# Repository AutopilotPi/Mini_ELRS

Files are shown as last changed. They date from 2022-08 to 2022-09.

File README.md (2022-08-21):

# Mini_ELRS

The repo is a hardware design for ELRS(https://github.com/ExpressLRS/ExpressLRS) by Kicad 6.0. The design aim to construct a 
mini elrs module which could drive brush motor directly.

There are 5 PWM channels in this board, 2 of them are with mos, and could connect to brush motor.

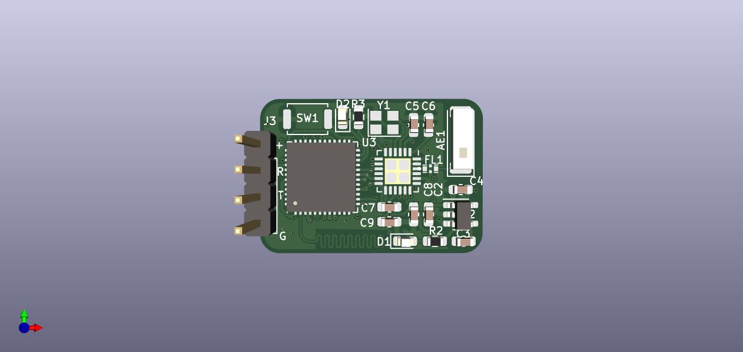
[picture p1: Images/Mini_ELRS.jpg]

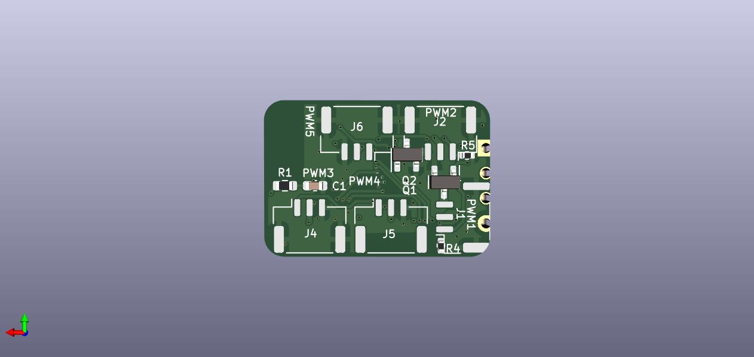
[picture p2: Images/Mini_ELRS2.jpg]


## License
Please notice that the license of this project is GPL 3.0. For hardware project, hope that you can share the changes if you make something different in the sch or pcb.

### reference
https://github.com/ExpressLRS/ExpressLRS-Hardware/tree/master/PCB/2400MHz/RX_Nano

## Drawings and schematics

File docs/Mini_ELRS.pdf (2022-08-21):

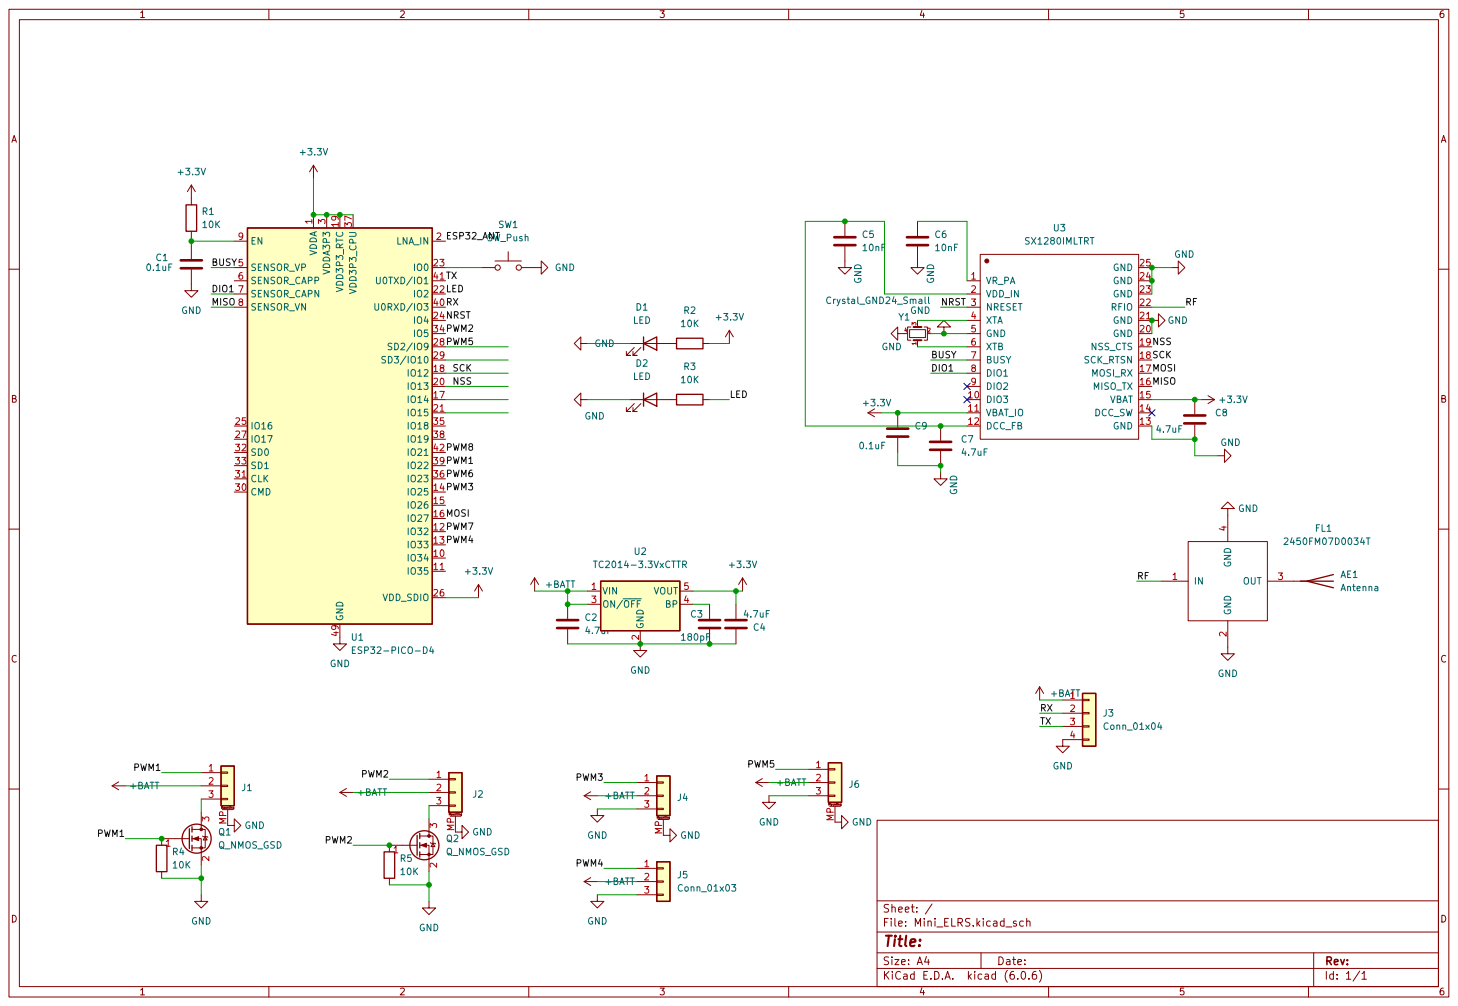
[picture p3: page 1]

NSS NRST MOSI PWM7 PWM6 PWM4 PWM3 ESP32_ANT RX

2 ON/~{OFF} 3 BP 4 VOUT 5 U2 TC2014-3.3VxCTTR GND GND

SCK RF BUSY DIO1 MISO

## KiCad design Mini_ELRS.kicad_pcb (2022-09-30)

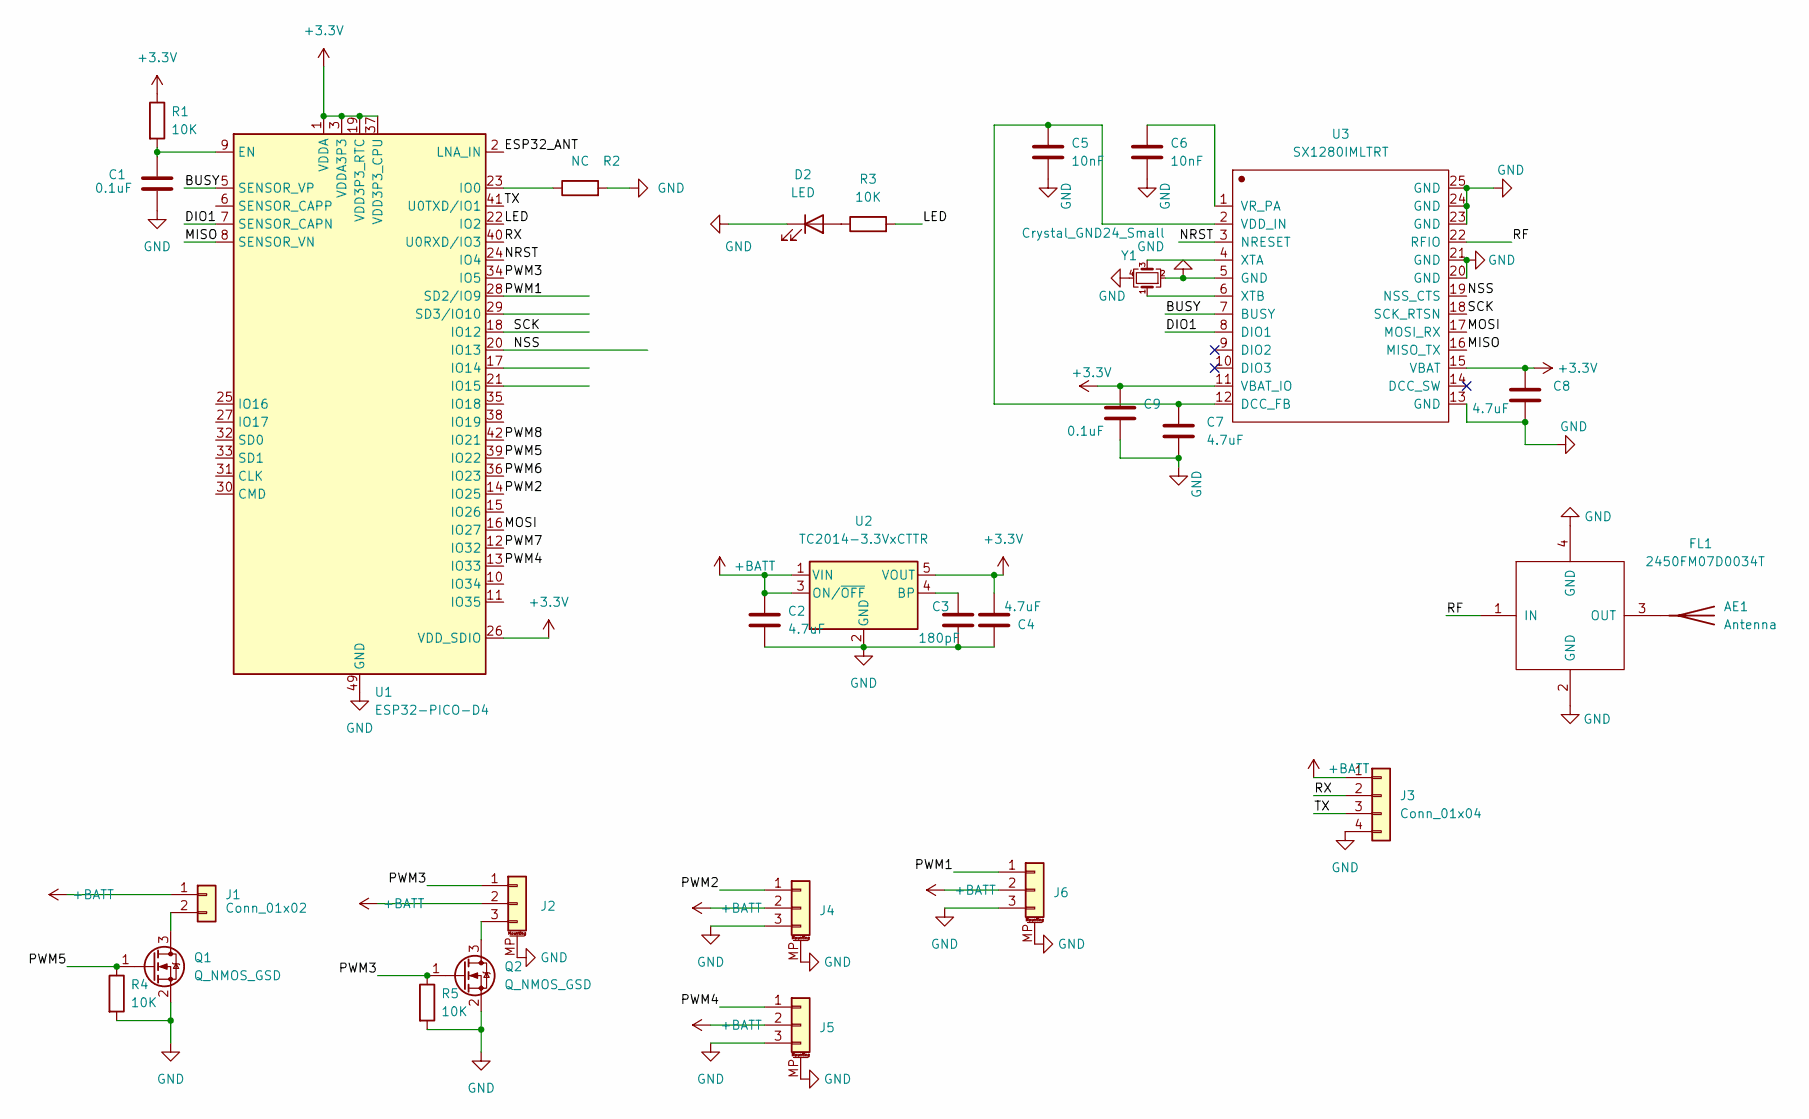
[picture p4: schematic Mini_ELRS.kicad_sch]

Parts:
AE1: Antenna; Johanson_2450AT43F0100
C1, C9: 0.1uF; C_0603_1608Metric
C2, C4, C7, C8: 4.7uF; C_0603_1608Metric
C3: 180pF; C_0603_1608Metric
C5, C6: 10nF; C_0603_1608Metric
D2: LED; LED_0603_1608Metric
FL1: 2450FM07D0034T; FILTER-SMD_4P-L1.0-W0.5-L
J1: Conn_01x02; PinHeader_2x01_P2.54mm_Vertical
J2, J4, J5, J6: Conn_01x03_MountingPin; Molex_CLIK-Mate_502386-0370_1x03-1MP_P1.25mm_Horizontal
J3: Conn_01x04; PinHeader_1x04_P2.54mm_Vertical
Q1, Q2: Q_NMOS_GSD; SOT-23
R1, R3, R4, R5: 10K; R_0603_1608Metric
R2: NC; R_0603_1608Metric
U1: ESP32-PICO-D4; QFN-48-1EP_7x7mm_P0.5mm_EP5.3x5.3mm
U2: TC2014-3.3VxCTTR; SOT-23-5
U3: SX1280IMLTRT; QFN-24-1EP_4x4mm_P0.5mm_EP2.65x2.65mm
Y1: Crystal_GND24_Small; Crystal_SMD_2520-4Pin_2.5x2.0mm

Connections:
+3V3: C4.1, C8.1, C9.1, R1.1, U1.1 (VDDA), U1.3 (VDDA3P3), U1.4 (VDDA3P3), U1.19 (VDD3P3_RTC), U1.26 (VDD_SDIO), U1.37 (VDD3P3_CPU), U1.43 (VDDA), U1.46 (VDDA), U2.5 (VOUT), U3.11 (VBAT_IO), U3.15 (VBAT)
+BATT: C2.1, J1.1, J2.2, J3.1, J4.2, J5.2, J6.2, U2.1 (VIN), U2.3 (ON/~OFF)
/BUSY: U1.5 (SENSOR_VP), U3.7 (BUSY)
/DIO1: U1.7 (SENSOR_CAPN), U3.8 (DIO1)
/ESP32_ANT: U1.2 (LNA_IN)
/LED: R3.2, U1.22 (IO2)
/MISO: U1.8 (SENSOR_VN), U3.16 (MISO_TX)
/MOSI: U1.16 (IO27), U3.17 (MOSI_RX)
/NRST: U1.24 (IO4), U3.3 (NRESET)
/NSS: U1.20 (IO13), U3.19 (NSS_CTS)
/PWM1: J6.1, U1.28 (SD2/IO9)
/PWM2: J4.1, U1.14 (IO25)
/PWM3: J2.1, Q2.1 (G), R5.1, U1.34 (IO5)
/PWM4: J5.1, U1.13 (IO33)
/PWM5: Q1.1 (G), R4.1, U1.39 (IO22)
/PWM6: U1.36 (IO23)
/PWM7: U1.12 (IO32)
/PWM8: U1.42 (IO21)
/RF: FL1.1 (IN), U3.22 (RFIO)
/RX: J3.2, U1.40 (U0RXD/IO3)
/SCK: U1.18 (IO12), U3.18 (SCK_RTSN)
/TX: J3.3, U1.41 (U0TXD/IO1)
GND: C1.2, C2.2, C3.2, C4.2, C5.2, C6.2, C7.2, C8.2, C9.2, D2.1 (K), FL1.2 (GND), FL1.4 (GND), J2.MP (MountPin), J3.4, J4.3, J4.MP (MountPin), J5.3, J5.MP (MountPin), J6.3, J6.MP (MountPin), Q1.2 (S), Q2.2 (S), R2.2, R4.2, R5.2, U1.49 (GND), U2.2 (GND), U3.5 (GND), U3.13 (GND), U3.20 (GND), U3.21 (GND), U3.23 (GND), U3.24 (GND), U3.25 (GND), Y1.2, Y1.4
unnamed: AE1.1 (A), FL1.3 (OUT)
unnamed: C1.1, R1.2, U1.9 (EN)
unnamed: C3.1, U2.4 (BP)
unnamed: C5.1, C7.1, U3.2 (VDD_IN), U3.12 (DCC_FB)
unnamed: C6.1, U3.1 (VR_PA)
unnamed: D2.2 (A), R3.1
unnamed: J1.2, Q1.3 (D)
unnamed: J2.3, Q2.3 (D)
unnamed: R2.1, U1.23 (IO0)
unnamed: U3.4 (XTA), Y1.3
unnamed: U3.6 (XTB), Y1.1

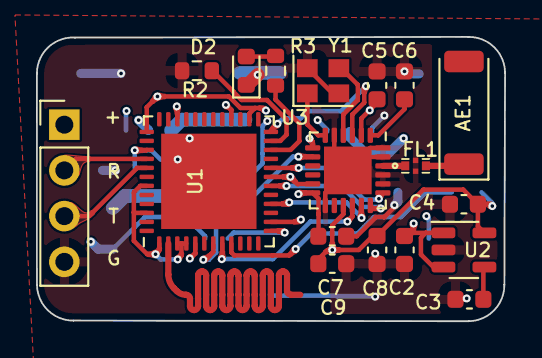
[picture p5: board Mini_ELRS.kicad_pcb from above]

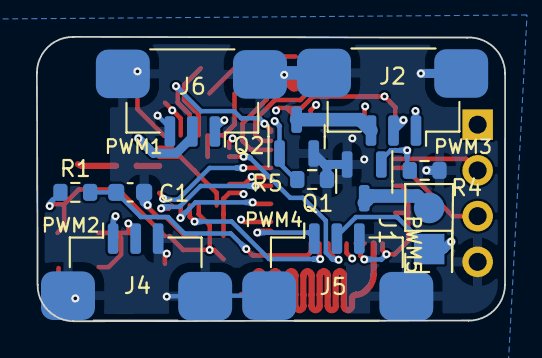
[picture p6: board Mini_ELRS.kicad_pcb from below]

Board: 4 copper layers, 26.0 x 15.8 mm, 29 parts (11 on the bottom side), 30 nets.

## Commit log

2022-04-04 remove the copper in the cutting area, which would cause the lack of connection after cutting
    [Mini_ELRS.kicad_pcb]
2022-05-25 v0.9 test
    [Mini_ELRS.kicad_pcb]
2022-08-21 update esp32_with_mos
    [Mini_ELRS.kicad_pcb, Mini_ELRS.kicad_sch]
2022-08-21 fix the 2.54 connector package.
    [Mini_ELRS.kicad_pcb]
2022-09-06 swap some pwm pins net name
    [Mini_ELRS.kicad_pcb, Mini_ELRS.kicad_sch]
2022-09-20 remove something unncessary
    [Mini_ELRS.kicad_pcb, Mini_ELRS.kicad_sch]
2022-09-30 finished pcb. using normal layer stack
    [Mini_ELRS.kicad_pcb, Mini_ELRS.kicad_sch]
2022-12-25 edit the value of pulldown res of IO5
    [Mini_ELRS.kicad_sch]
